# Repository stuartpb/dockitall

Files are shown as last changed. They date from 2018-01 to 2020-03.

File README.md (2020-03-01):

# dockitall Parametric Charging Dock

This is a parametric design I made to have a dock I could place my Google Pixel 2 XL into now that I can't just use wireless charging. (I'm still holding out for a Pixel 5 XL that has it.)

## Original phone and cable (not included)

The included model was designed to fit [an AmazonBasics USB-C cable](https://www.amazon.com/gp/product/B01GGKZ1VA/), and a Google Pixel 2 XL in a [slim TPU case](https://www.amazon.com/gp/product/B0756884QS/). The base is designed to fit an ordinary 80cm equilateral triangular anti-slip pad to stick it to your desk - [here](https://www.amazon.com/dp/B07CTQST6R) is a package on Amazon with one.

## Parameters

These parameters (as seen in the SCAD file linked as source):

### The phone / case

- Device with an 80x10mm footprint
  - footprint corners have bevels of 3mm radius around the front and 5mm radius around the back
- device face
  - outside profile has a bottom corner radius of 8mm
  - the front of the device is wrapped around for 4mm (to the edges of a ~72mm screen)
  - the screen has a corner radius of 5.5mm (or less - this is the outer radius we surround)
  - the screen is 10mm from the edge (lip_height)
  - there is a 32mm wide speaker 6mm from the screen (lip_cleft_width,lip_cleft_height)

### The USB cable

- the plug
  - head is 10.7x5mm, with perfectly round corners (or at least close enough to fit)
 - sits 16.5mm beneath the surface (being 18mm long, minus 1.5mm to raise it to where the phone sits in the case)
- cable track going out the back is 4.2 mm

## Etcetera

The baked model has other discretionary parameters not included here.

If you'd like to tweak these before printing to better fit your on-hand hardware, see "Customizing the SCAD file" below.

## Assembly

### Through-hole: hourglass design (default)

This design assumes that your plug is not that much wider than your device is thick: if that isn't the case, when customizing the SCAD file (described below), you might need to go for the "Open channel" design (described in the next section).

To insert the cable in this design, turn it diagonally into the figure-eight-shaped hole in the bottom, push/pull it through (if doing this requires too much force, see "Customizing the SCAD file" to add tolerance to that channel / adjust its size for your cable's head/plug).

### Through-hole: open-channel design

If you customize the model to use the "Open channel" style, then simply push the cable through the hole in the back. If the full plug / head can't get through (to the point that you can pull cable through freely), you may need to customize the plug measurements and try again (see note below about testing modules to perform focused experiments with this).

### Seating the cable and dock

Once the plug is through, rotate it into the horizontal slot, then push/pull it into place until it fits against the bottom of the channel.

Thread the cable through the channel in the base, then place the sticky pad on the base to hold it in place (both the cable in the base, and the base to the desk).

# Print instructions

## Using the models here

A "onepiece" model is included for single-material printing. The parameters of this model (and the MMU models) are rendered here from the parameters described above.

I've tested the MMU version (in an earlier revision with minor differences) on an MK3S/MMU2S, in yellow and black PETG. I used black for both a stripe and the base. (Transitioning between these materials needed a lot of purge to get a clean yellow - I'm still experimenting at around 300mm).

### MMU

MMU owners can use the a_stripes, b_stripes, and base_plate models to print the dock in two different colors of diagonal stripe, as well as the base (which may share a material with one of the stripe colors, if desired).

## Customizing the SCAD file

You'll need a relatively new version of OpenSCAD to be compatible with the implementation of curves used in this file: you can follow the installation instructions / download it from http://www.openscad.org/downloads.html

Once you have OpenSCAD, download "dockitall.scad" from here and open it up.

## Variable customization

The customizable variables are at the top of the file, under Thingiverse-Customizer-like headings.

## Module selection

Module rendering is done by uncommenting a final call at the bottom of the file (under the "Entry points" block heading).

## Test models

If customizing the variables in the model for your own, rather than having to print entire sacrificial drafts as you dial your measurements in, you can print small pieces to test your settings by rendering the test_dockblock and cable_test modules.

When printing test_dockblock, you can customize the region of the model that you test with the test_bottom and test_height parameters.

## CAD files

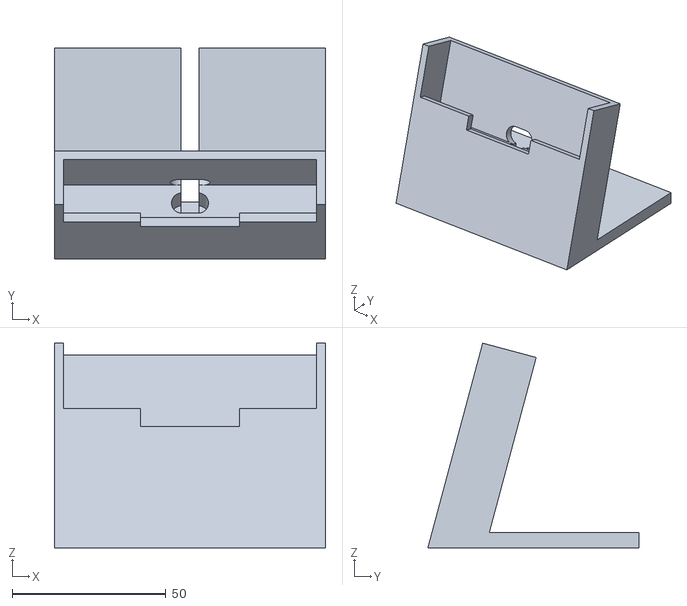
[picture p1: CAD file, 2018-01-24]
dockitall.stl
88.0 x 68.6 x 66.5

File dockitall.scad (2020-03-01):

//!OpenSCAD
// title      : Dockitall Parametric Charging Dock
// author     : Stuart P. Bentley (@stuartpb)
// version    : 0.2.0
// file       : dockitall.scad

/* [Cosmetic] */

// How wide to make the multi-material stripes.
stripe_width = 14;

/* [Measurements] */

// These measurements are based on my Pixel 2 XL in a
// Aeske Ultra slim case, and an Amazon Basics cable.

// The width of the device.
device_width = 80;
// The depth (thickness) of the device.
device_depth = 10;

// The radius of the device's front edges.
device_front_edge_bevel = 3;
// The radius of the device's back edges.
device_back_edge_bevel = 5;

// The radius of the bottom left and right corners.
device_bottom_corner_radius = 8;

// The width of the front opening for the screen.
screen_width = 72;

// The radius of the corner that will descend to the lip.
screen_corner_radius = 5.5;

// Offset of the port from the center of the bottom.
port_x_offset = 0;
// Y offset is positive ("up") going closer to the face.
port_y_offset = 0;
// Z offset is for the port's inset to things like a phone case,
// raising the plug accordingly.
port_z_offset = 1.5;

// The width of the USB plug.
plug_width = 10.7;
// The depth (thickness) of the USB plug.
plug_depth = 5;
// The roundness of the USB plug (currently only supports plug_depth/2 and 0).
plug_radius = plug_depth/2;
// The length of the plug before tapering off to the cable.
plug_length = 18;
// The diameter of the cable immediately following the end of the plug.
  // Note that the immediate end of the plug really only matters in the
  // cradle used by the "open channel" design. If using the bottom-hole instead,
  // you could also go with 3.5 (the gauge of the cable after the neck),
  // but this gives a little extra "breathing room" regardless.
cable_gauge = 4.20;

/* [Tolerances] */

// How much extra space to leave around the device.
device_tolerance = .05;
// How much extra space to leave around the through-hole for the plug.
  // (If you use the "open channel" back-face through-hole design,
  // you might want this extra big to allow for maneuvering around the lip.)
through_tolerance = .1;
// How much extra space to leave around the plug.
plug_tolerance = 0;
// How much extra space to leave around the cable.
cable_tolerance = 0;

/* [Parameters] */

// Whether top surfaces should be flat / parallel to the base.
level_tops = false;

// Whether the cable should be laid into the case from the back.
open_channel = false;

// What angle to recline the phone at (from a straight-up zero degrees).
recline_angle = 15;

// The height of the dock underneath the phone.
// Should be at least as long as the plug, plus room for the cable to turn.
chin_height = 32;

// The height of the lip in front of the device.
lip_height = 10;

// The thickness of the bottom base.
base_thickness = 6.4;

// The corner radius of the back corner.
base_corner_radius = device_front_edge_bevel;

// The thickness of the walls.
wall_thickness = 3;

// The radius of the "top" corner.
cheek_front_edge_bevel = 8;
cheek_back_edge_bevel = 3;

// How wide of a gap to put in the middle of the lip (eg. for a speaker).
lip_cleft_width = 32;
// The height of the lip within the cleft (ie. beneath the speaker).
lip_cleft_height = 6;

lip_cleft_fillet = 3;
lip_cleft_bevel = 3;

// The height above the lip that the cheek extends around the front.
front_cheek_height = (screen_width-lip_cleft_width)/2;
front_cheek_bevel = 3;
front_top_corner_bevel = 5;
// The radius of the curve from the back to the front cheeks.
front_fillet = 2;

back_height = 50;
back_cheek_height = back_height;

back_top_corner_bevel = 3;
side_back_corner_bevel = 3;

/* [Testing] */

// The region to render when printing a test dockblock.
test_bottom = 10;
test_height = 40;

/* [Rendering] */

// Epsilon value for enveloping differences
eps = 1/128;
//$fn=24;

$fa = 1;
$fs = 1;

/* [Hidden] */

device_depth_total = device_depth + 2*device_tolerance;
dock_depth = device_depth_total + 2*wall_thickness;
device_width_total = device_width + 2*device_tolerance;
dock_width = device_width_total + 2*wall_thickness;
dock_length = back_height + chin_height;
plug_width_total = plug_width + plug_tolerance;
plug_depth_total = plug_depth + plug_tolerance;
cable_total = cable_gauge + 2*cable_tolerance;

// How much extra length the dock needs to meet the
// XY plane when angled.
chin_hem = tan(recline_angle)*dock_depth/2;

base_length = dock_width * cos(30);

/*
///// Code /////
*/

/* Rendering components */

function curve_points(o,d,cw=true) =
  (abs(d[0]) > 0 && abs(d[1]) > 0) ?
    // number of facets for 1/4 circle ($fn if defined)
    (let (n=ceil(($fn>0 ? $fn
      // if $fn is not defined, either the maximum under $fa,
      : min(360/$fa,
        // or the number of facets for $fs at this size
        max(abs(d[0]),abs(d[1])) * 2*PI/$fs)
      )/4),xy = ((d[0]>0) == (d[1]>0)) == cw)
    // for each point on the curve,
    [for (i=[(xy?0:n) : (xy?1:-1) : (xy?n:0)])
    // return its coordinate
      [o[0]+sin(90*(i/n))*d[0], o[1]+cos(90*(i/n))*d[1]]]) : [o];

module round_4corners_rect(w,h,tr_r,br_r,bl_r,tl_r) {
  assert(w>=max(br_r+bl_r,tl_r+tr_r));
  assert(h>=max(tr_r+br_r,bl_r+tl_r));

  if (w>0 && h>0) polygon([
    each curve_points(
      [w/2 - tr_r, h/2 - tr_r], [tr_r, tr_r]),
    each curve_points(
      [w/2 - br_r, -h/2 + br_r], [br_r, -br_r]),
    each curve_points(
      [-w/2 + bl_r, -h/2 + bl_r], [-bl_r, -bl_r]),
    each curve_points(
      [-w/2 + tl_r, h/2 - tl_r], [-tl_r, tl_r])
  ]);
}

module round_tbcorners_rect(w,h,t_r,b_r) {
  round_4corners_rect(w,h,t_r,b_r,b_r,t_r);
}
module round_lrcorners_rect(w,h,l_r,r_r) {
  round_4corners_rect(w,h,r_r,r_r,l_r,l_r);
}

module round_corner_rect(w,h,r) {
  round_4corners_rect(w,h,r,r,r,r);
}

/* Dock design components */

module device_cross_section() {
  round_tbcorners_rect(device_width,device_depth,device_back_edge_bevel,device_front_edge_bevel);
}

module dock_perimeter() {
  difference() {
    offset(delta=device_tolerance + wall_thickness) device_cross_section();
    offset(delta=device_tolerance) device_cross_section();
  }
}

module dock_walls () {
  translate([0,0,-chin_hem])
  linear_extrude(2*chin_hem+dock_length, convexity = 10) dock_perimeter();
}

module plughole() {
  round_corner_rect(plug_width,plug_depth,plug_radius);
}

module backhole() {
  rotate([90,0,0])
  multmatrix([[1,0,0,0], [0,1,level_tops?-tan(recline_angle):0,0],
      [0,0,1,0],[0,0,0,1]])
  translate([port_x_offset,
    chin_hem + chin_height + plug_depth/2 + through_tolerance,
    -plug_length])
  
    linear_extrude(plug_length)
    offset(delta=through_tolerance)
    plughole();
}

module throughhole() {
  // When the cable will be coming through the backhole
  if (open_channel) {
    // Just channel for the cable, below the plug holder and coming out the back
    translate([0,0,-chin_hem]) linear_extrude(chin_height + chin_hem + plug_depth)
      translate([port_x_offset, port_y_offset-cable_total/2 + dock_depth/2]) 
      round_corner_rect(cable_total, dock_depth, cable_total/2);
  // Hourglass hole if plug can't fit vertically
  } else if (plug_width + 2*through_tolerance > device_depth_total) {
    through_r = plug_radius+through_tolerance;
    a = plug_width/2 - plug_radius;
    b = plug_depth/2 - plug_radius;
    hypo = sqrt(a*a+b*b);
    tilt = asin((device_depth_total/2-through_r)/hypo);
    angle = tilt-atan(b/a);
    translate([port_x_offset, port_y_offset, -chin_hem])
      linear_extrude(chin_height + chin_hem + plug_depth)
      union () {
        rotate(angle) offset(delta=through_tolerance) plughole($fn=24);
        rotate(-angle) offset(delta=through_tolerance) plughole($fn=24);
        square([cos(tilt) * 2 * (hypo+through_tolerance),device_depth_total], center=true);
      }
  // Vertical hole if plug can fit
  } else {
    translate([port_x_offset, port_y_offset, -chin_hem])
      linear_extrude(chin_height + chin_hem + plug_depth)
        rotate(90) offset(delta=through_tolerance) plughole($fn=24);
  }
}

module dock_back_face() {
  translate([0,dock_length/2])
    round_tbcorners_rect(dock_width,dock_length,back_top_corner_bevel,0);
}

module fillet(r,o=eps) {
  polygon([[0,0],each curve_points([r+eps,r+eps],[-r-eps,-r-eps])]);
}

function reverse(a) = [for (i=[len(a)-1:-1:0]) a[i]];
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

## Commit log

2018-01-24 Initial commit of dockitall.scad
    [dockitall.scad, dockitall.stl]
2018-01-24 Fix cable tolerance
    Cable tolerance is now applied consistently and correctly.
    Previously, cable tolerance was halved for everything but the through-hole for the plug.
    Correspondingly, default value for cable tolerance has been halved (to match its old behavior), and the through-hole now uses the device's tolerance value instead.
    [dockitall.scad, dockitall.stl]
2020-01-10 Use triangle instead of square as base
    [dockitall.scad]
2020-01-10 Tweak measurements
    [dockitall.scad]
2020-01-18 Add dual-extrusion striping variants
    [dockitall.scad]
2020-01-18 Fudge measurements a bit
    [dockitall.scad]
2020-01-19 First work into linear-extrusion-based-dock-block
    [dockitall.scad]
2020-01-19 Use rounded corner module more widely
    [dockitall.scad]
2020-01-21 Most of the assembly complete
    [dockitall.scad]
2020-01-21 More progress
    [dockitall.scad]
2020-01-21 A little more work...
    [dockitall.scad]
2020-01-21 Much closer parameters
    [dockitall.scad]
2020-01-23 First shipping prototype
    [dockitall.scad]
2020-01-23 Minor tweaks
    - make $fn a factor of 4 to not mess up the hull assumptions about bounding boxes
    - slightly more tolerance & screen dimensions based on testing
    - use delta to simplify offset geometry
    [dockitall.scad]
2020-01-23 Attempt to make vertical hole
    [dockitall.scad]
2020-01-24 Screwy wrong trig that looks right
    [dockitall.scad]
2020-01-24 Even more wildly wrong
    [dockitall.scad]
2020-01-24 Fixed trig
    The issue was that I was effectively subtracting through_tolerance twice,
    as plug_width did not factor it in.
    [dockitall.scad]
2020-01-25 Everything good enough to ship
    [dockitall.scad]
2020-01-25 Imperfect curve-to algorithm
    [dockitall.scad]
2020-01-25 Implemented curve-to algorithm
    Struggling to clean/generalize throughhole silhouette
    [dockitall.scad]
2020-01-25 Successfully generalize throughhole
    [dockitall.scad]
2020-01-30 Fix throughhole math, modernize some variables
    [dockitall.scad]
2020-01-30 Almost-perfect dock design
    I sent this one off to print before realizing I'd forgotten to account for the front cheeks in the profile (hence why the cheek bevel is zero).
    [dockitall.scad]
2020-02-29 Clean up some lingering issues
    [dockitall.scad]
2020-03-01 Fix open-channel design
    [dockitall.scad]
2020-03-01 Tweak a couple parameters for good measure
    [dockitall.scad]
